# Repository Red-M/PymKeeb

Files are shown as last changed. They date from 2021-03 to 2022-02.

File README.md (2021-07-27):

# PymKeeb
## What is this?
I'm getting fed up with the options for keyboards and there isn't anything that I want 100%, everything is a compromise between form factor, customizability and availability.
So I'm making my own keyboard.

## Design choices
I don't want to limit end users on customizing their boards or choosing what they want, so I'll be maximumizing that as much as possible while also giving the option for changing things like the size and layout in forks or derivatives.
I don't want the host device to make choices for the user so limiting things behind having a certain OS is not ok, eg, software that runs on the host device.

## Goals
- USB C input
    - This is just a requirement at this point
- Layout
    - Full size layout with 4 extra switches above the numpad to set for macros
    - Indicator lights need to be above the numbpad
    - Two LEDs per switch, I want extra light
- Switches
    - Hot swap switches
        - Khali hotswaps allow for MX style switches to swap in and out
            - Has a number of switch variants that will fit
- Firmware/Software
    - Firmware only, no host device software at all.
    - Firmware updates should be really simple, no custom software, just drag and drop in DFU or similar
    - CapsLock indicator is in key and matches RGB light of switch
    - All on keyboard with function key similar to ducky keyboards
    - Brightness toggle
    - Macro support
    - NKRO
        - I don't want artifacts or ghosting at all

## Software for designing/building the board
KiCAD, you're going to need KiCAD.
I'm also learning KiCAD so please if you see something I've done that could be done a better way, please file at least an issue or go a head and fix it in a PR.
If it makes sense, I'll merge it in, no questions asked.

## Firmware
This is largely going to depend on what MCU I choose and right now all I know is that the pico or an STMF4 might be the best options.

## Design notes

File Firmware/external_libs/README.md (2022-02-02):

You're going to need these libraries:
- adafruit_bus_device
- adafruit_display_shapes
- adafruit_display_text
- adafruit_hid
- adafruit_rgb_display
- asyncio
- adafruit_dotstar
- adafruit_ducky
- adafruit_st7789
- adafruit_ticks

Make sure they're also in the lib directory of the CIRCUITPY drive after you copy everything from the Firmware directory.

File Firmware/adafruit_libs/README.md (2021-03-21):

You're going to need these libraries:
- adafruit_bus_device
- adafruit_hid
- adafruit_mcp230xx
- https://github.com/adafruit/Adafruit_CircuitPython_DotStar

Make sure they're also in the lib directory of the CIRCUITPY drive after you copy everything from the Firmware directory.

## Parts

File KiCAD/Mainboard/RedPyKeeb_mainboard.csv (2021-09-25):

Reference | Quantity | Value | Footprint | Datasheet | Digikey Part No | Mouser No | element14 code
C6 | 1 | EEE-FN1C102UV | Capacitor_SMD:CP_Elec_10x10 |  | 10-EEE-FN1C102UVCT-ND | 667-EEE-FN1C102UV
D0,0 D0,1 D0,2 D0,3 D0,4 D0,5 D1,0 D1,1 D1,2 D1,3 D1,4 D1,5 D2,0 D2,1 D2,2 D2,3 D2,4 D2,5 D3,0 D3,1 D3,2 D3,3 D3,4 D3,5 D4,0 D4,1 D4,2 D4,3 D4,4 D5,0 D5,1 D5,2 D5,3 D5,4 D6,0 D6,1 D6,2 D6,3 D6,4 D7,0 D7,1 D7,2 D7,3 D7,4 D8,0 D8,1 D8,2 D8,3 D8,4 D8,5 D9,0 D9,1 D9,2 D9,3 D9,4 D9,5 D10,0 D10,1 D10,2 D10,3 D10,4 D10,5 D11,0 D11,1 D11,2 D11,3 D11,4 D11,5 D12,0 D12,1 D12,2 D12,3 D13,1 D13,2 D14,0 D14,1 D14,3 D14,6 D15,0 D15,1 D15,3 D15,5 D15,6 D16,0 D16,1 D16,3 D16,4 D16,5 D16,6 D17,0 D17,1 D17,3 D17,4 D17,5 D17,6 D18,0 D18,1 D18,3 D18,4 D18,5 D18,6 D19,0 D19,1 D19,3 D19,4 D19,6 D20,0 D20,1 | 108 | 1N4148W-7-F | keyboard_parts:D_SOD123_axial |  | 1N4148W-FDICT-ND | 621-1N4148W-F | 2306363
J1 | 1 | Conn_02x20_Top_Bottom | Connector_PinHeader_2.54mm:PinHeader_2x20_P2.54mm_Vertical_SMD | ~ |  | 200-SSM120LMDVBE
LD0,0 LD0,1 LD0,2 LD0,3 LD0,4 LD0,5 LD1,0 LD1,1 LD1,2 LD1,3 LD1,4 LD1,5 LD2,0 LD2,1 LD2,2 LD2,3 LD2,4 LD2,5 LD3,0 LD3,1 LD3,2 LD3,3 LD3,4 LD3,5 LD4,0 LD4,1 LD4,2 LD4,3 LD4,4 LD5,0 LD5,1 LD5,2 LD5,3 LD5,4 LD6,0 LD6,1 LD6,2 LD6,3 LD6,4 LD7,0 LD7,1 LD7,2 LD7,3 LD7,4 LD8,0 LD8,1 LD8,2 LD8,3 LD8,4 LD8,5 LD9,0 LD9,1 LD9,2 LD9,3 LD9,4 LD9,5 LD10,0 LD10,1 LD10,2 LD10,3 LD10,4 LD10,5 LD11,0 LD11,1 LD11,2 LD11,3 LD11,4 LD11,5 LD12,0 LD12,1 LD12,2 LD12,3 LD13,1 LD13,2 LD14,0 LD14,1 LD14,3 LD14,6 LD15,0 LD15,1 LD15,3 LD15,5 LD15,6 LD16,0 LD16,1 LD16,3 LD16,4 LD16,5 LD16,6 LD17,0 LD17,1 LD17,3 LD17,4 LD17,5 LD17,6 LD17,7 LD18,0 LD18,1 LD18,3 LD18,4 LD18,5 LD18,6 LD18,7 LD19,0 LD19,1 LD19,3 LD19,4 LD19,6 LD19,7 LD20,0 LD20,1 LD20,7 LD3,5,0 LD3,5,1 | 114 | APA102 2020 | Custom_pico:LED-APA102-2020 | http://www.led-color.com/upload/201604/APA102-2020%20SMD%20LED.pdf | 1528-1826-ND | 485-3587

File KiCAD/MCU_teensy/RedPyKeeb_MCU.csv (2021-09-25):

Reference | Quantity | Value | Footprint | Datasheet | Digikey Part No | Mouser No | element14 code
C1 C2 | 2 | 0805B101K100CT | Capacitor_SMD:C_0805_2012Metric_Pad1.18x1.45mm_HandSolder |  |  | 791-0805B101K100CT | 1856401
J0 | 1 | Conn_01x04 | Connector_JST:JST_EH_S4B-EH_1x04_P2.50mm_Horizontal |  | 1528-2751-ND | 485-3955
J1 | 1 | Conn_02x20_Top_Bottom | Connector_PinHeader_2.54mm:PinHeader_2x20_P2.54mm_Vertical | ~ |  | 649-95278-102-40LF
J2 | 1 | Conn_01x04 | Connector_JST:JST_EH_S7B-EH_1x07_P2.50mm_Horizontal |  | 1528-2751-ND | 485-3955
R1 | 1 | ERJ-6RED2003V | Resistors_SMD:R_0805_HandSoldering | ~ |  | 667-ERJ-6RED2003V
U0 | 1 | Teensy4.1 | Custom_pico:Teensy41 |  |  | 474-DEV-16771
U1 | 1 | TXS0104ED | Package_SO:SOIC-14_3.9x8.7mm_P1.27mm | https://www.ti.com/lit/ds/symlink/txs0104e.pdf | 296-34699-5-ND | 595-TXS0104ED | TXS0104ED

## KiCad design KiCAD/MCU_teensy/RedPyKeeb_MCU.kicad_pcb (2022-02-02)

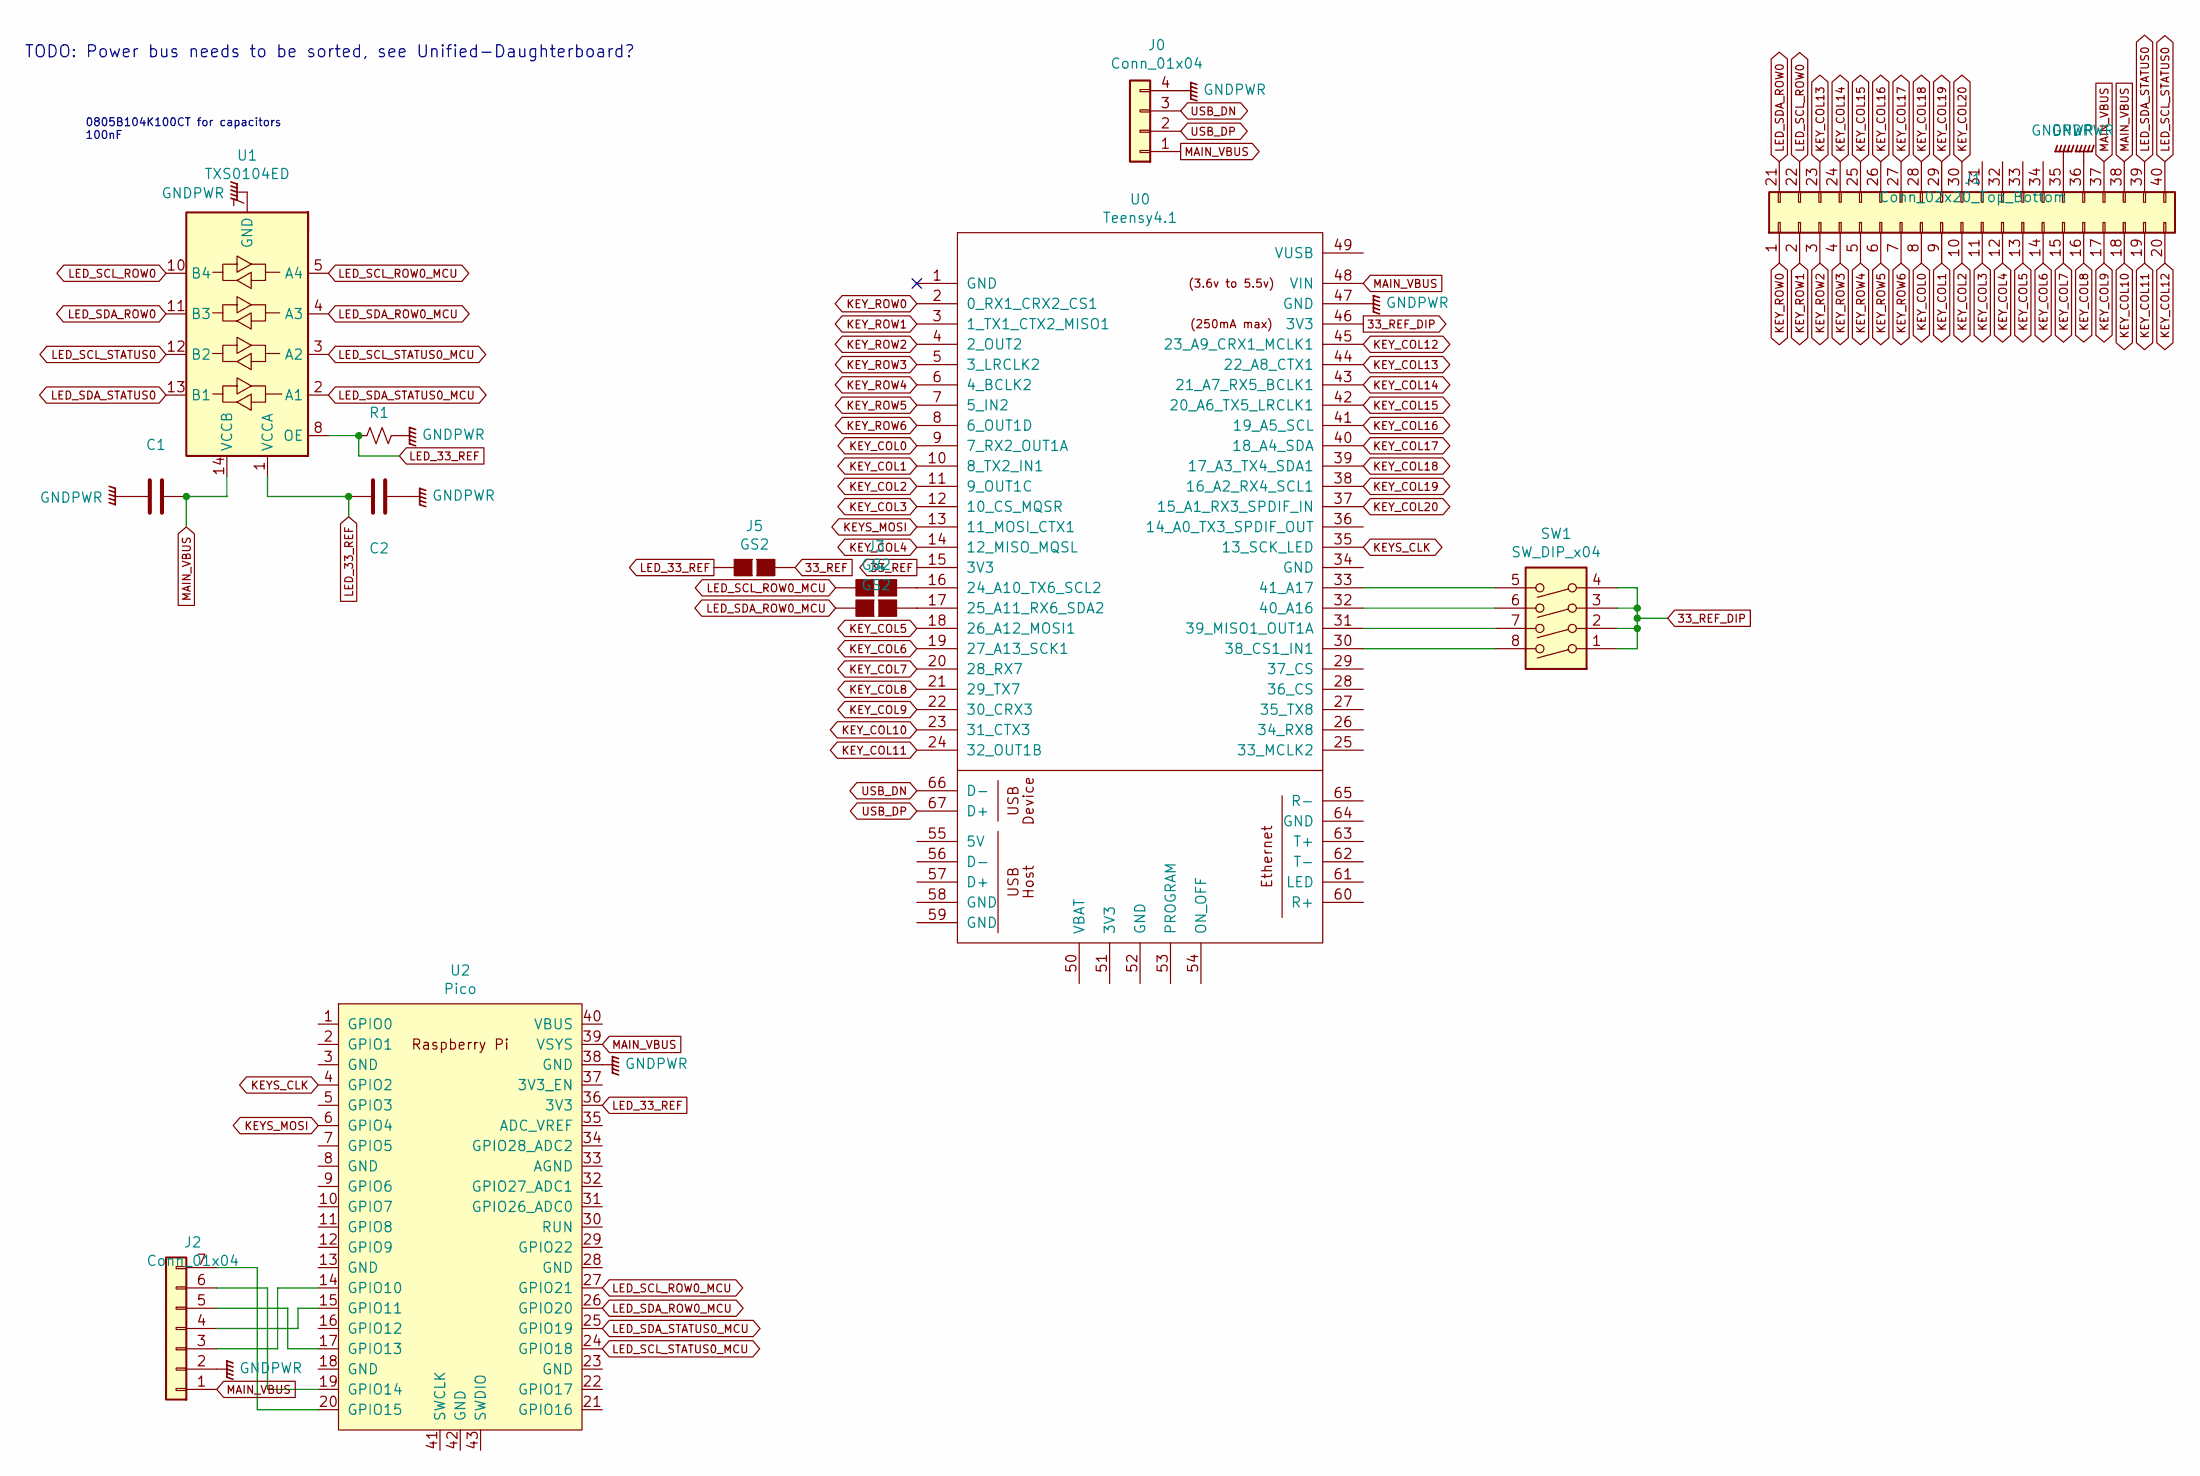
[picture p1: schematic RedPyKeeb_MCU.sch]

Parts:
C1, C2: 0805B101K100CT; C_0805_2012Metric_Pad1.18x1.45mm_HandSolder; Mouser No 791-0805B101K100CT
J0: Conn_01x04; JST_EH_S4B-EH_1x04_P2.50mm_Horizontal; Mouser No 485-3955
J1: Conn_02x20_Top_Bottom; PinHeader_2x20_P2.54mm_Vertical_SMD_doublesided; Mouser No 649-95278-102-40LF
J2: Conn_01x04; JST_EH_S7B-EH_1x07_P2.50mm_Horizontal; Mouser No 485-3955
J3, J4, J5: GS2
R1: ERJ-6RED2003V; R_0805_HandSoldering; Mouser No 667-ERJ-6RED2003V
SW1: SW_DIP_x04; SW_DIP_x4_W8.61mm_Slide_LowProfile_bothsides; Mouser No 653-A6SN-4104
U0: Teensy4.1; Teensy41; Mouser No 474-DEV-16771
U1: TXS0104ED; SOIC-14_3.9x8.7mm_P1.27mm; Mouser No 595-TXS0104ED
U2: Pico; RPi_Pico_SMD_TH

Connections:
33_REF: J5.1 (G1), U0.15 (3V3)
33_REF_DIP: SW1.1, SW1.2, SW1.3, SW1.4, U0.46 (3V3)
GNDPWR: C1.1, C2.1, J0.4, J1.35, J1.36, J2.2, R1.1, U0.47 (GND), U1.7 (GND), U2.38 (GND)
KEYS_CLK: U0.35 (13_SCK_LED), U2.4 (GPIO2)
KEYS_MOSI: U0.13 (11_MOSI_CTX1), U2.6 (GPIO4)
KEY_COL0: J1.8, U0.9 (7_RX2_OUT1A)
KEY_COL1: J1.9, U0.10 (8_TX2_IN1)
KEY_COL2: J1.10, U0.11 (9_OUT1C)
KEY_COL3: J1.11, U0.12 (10_CS_MQSR)
KEY_COL4: J1.12, U0.14 (12_MISO_MQSL)
KEY_COL5: J1.13, U0.18 (26_A12_MOSI1)
KEY_COL6: J1.14, U0.19 (27_A13_SCK1)
KEY_COL7: J1.15, U0.20 (28_RX7)
KEY_COL8: J1.16, U0.21 (29_TX7)
KEY_COL9: J1.17, U0.22 (30_CRX3)
KEY_COL10: J1.18, U0.23 (31_CTX3)
KEY_COL11: J1.19, U0.24 (32_OUT1B)
KEY_COL12: J1.20, U0.45 (23_A9_CRX1_MCLK1)
KEY_COL13: J1.23, U0.44 (22_A8_CTX1)
KEY_COL14: J1.24, U0.43 (21_A7_RX5_BCLK1)
KEY_COL15: J1.25, U0.42 (20_A6_TX5_LRCLK1)
KEY_COL16: J1.26, U0.41 (19_A5_SCL)
KEY_COL17: J1.27, U0.40 (18_A4_SDA)
KEY_COL18: J1.28, U0.39 (17_A3_TX4_SDA1)
KEY_COL19: J1.29, U0.38 (16_A2_RX4_SCL1)
KEY_COL20: J1.30, U0.37 (15_A1_RX3_SPDIF_IN)
KEY_ROW0: J1.1, U0.2 (0_RX1_CRX2_CS1)
KEY_ROW1: J1.2, U0.3 (1_TX1_CTX2_MISO1)
KEY_ROW2: J1.3, U0.4 (2_OUT2)
KEY_ROW3: J1.4, U0.5 (3_LRCLK2)
KEY_ROW4: J1.5, U0.6 (4_BCLK2)
KEY_ROW5: J1.6, U0.7 (5_IN2)
KEY_ROW6: J1.7, U0.8 (6_OUT1D)
LED_33_REF: C2.2, J5.2 (G2), R1.2, U1.1 (VCCA), U1.8 (OE), U2.36 (3V3)
LED_SCL_ROW0: J1.22, U1.10 (B4)
LED_SCL_ROW0_MCU: J3.2 (G2), U1.5 (A4), U2.27 (GPIO21)
LED_SCL_STATUS0: J1.40, U1.12 (B2)
LED_SCL_STATUS0_MCU: U1.3 (A2), U2.24 (GPIO18)
LED_SDA_ROW0: J1.21, U1.11 (B3)
LED_SDA_ROW0_MCU: J4.2 (G2), U1.4 (A3), U2.26 (GPIO20)
LED_SDA_STATUS0: J1.39, U1.13 (B1)
LED_SDA_STATUS0_MCU: U1.2 (A1), U2.25 (GPIO19)
MAIN_VBUS: C1.2, J0.1, J1.37, J1.38, J2.1, U0.48 (VIN), U1.14 (VCCB), U2.39 (VSYS)
unnamed: J2.3, U2.14 (GPIO10)
unnamed: J2.4, U2.15 (GPIO11)
unnamed: J2.5, U2.17 (GPIO13)
unnamed: J2.6, U2.19 (GPIO14)
unnamed: J2.7, U2.20 (GPIO15)
unnamed: J3.1 (G1), U0.16 (24_A10_TX6_SCL2)
unnamed: J4.1 (G1), U0.17 (25_A11_RX6_SDA2)
unnamed: SW1.5, U0.33 (41_A17)
unnamed: SW1.6, U0.32 (40_A16)
unnamed: SW1.7, U0.31 (39_MISO1_OUT1A)
unnamed: SW1.8, U0.30 (38_CS1_IN1)
USB_DN: J0.3, U0.66 (D-)
USB_DP: J0.2, U0.67 (D+)

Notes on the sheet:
TODO: Power bus needs to be sorted, see Unified-Daughterboard?
0805B104K100CT for capacitors 100nF

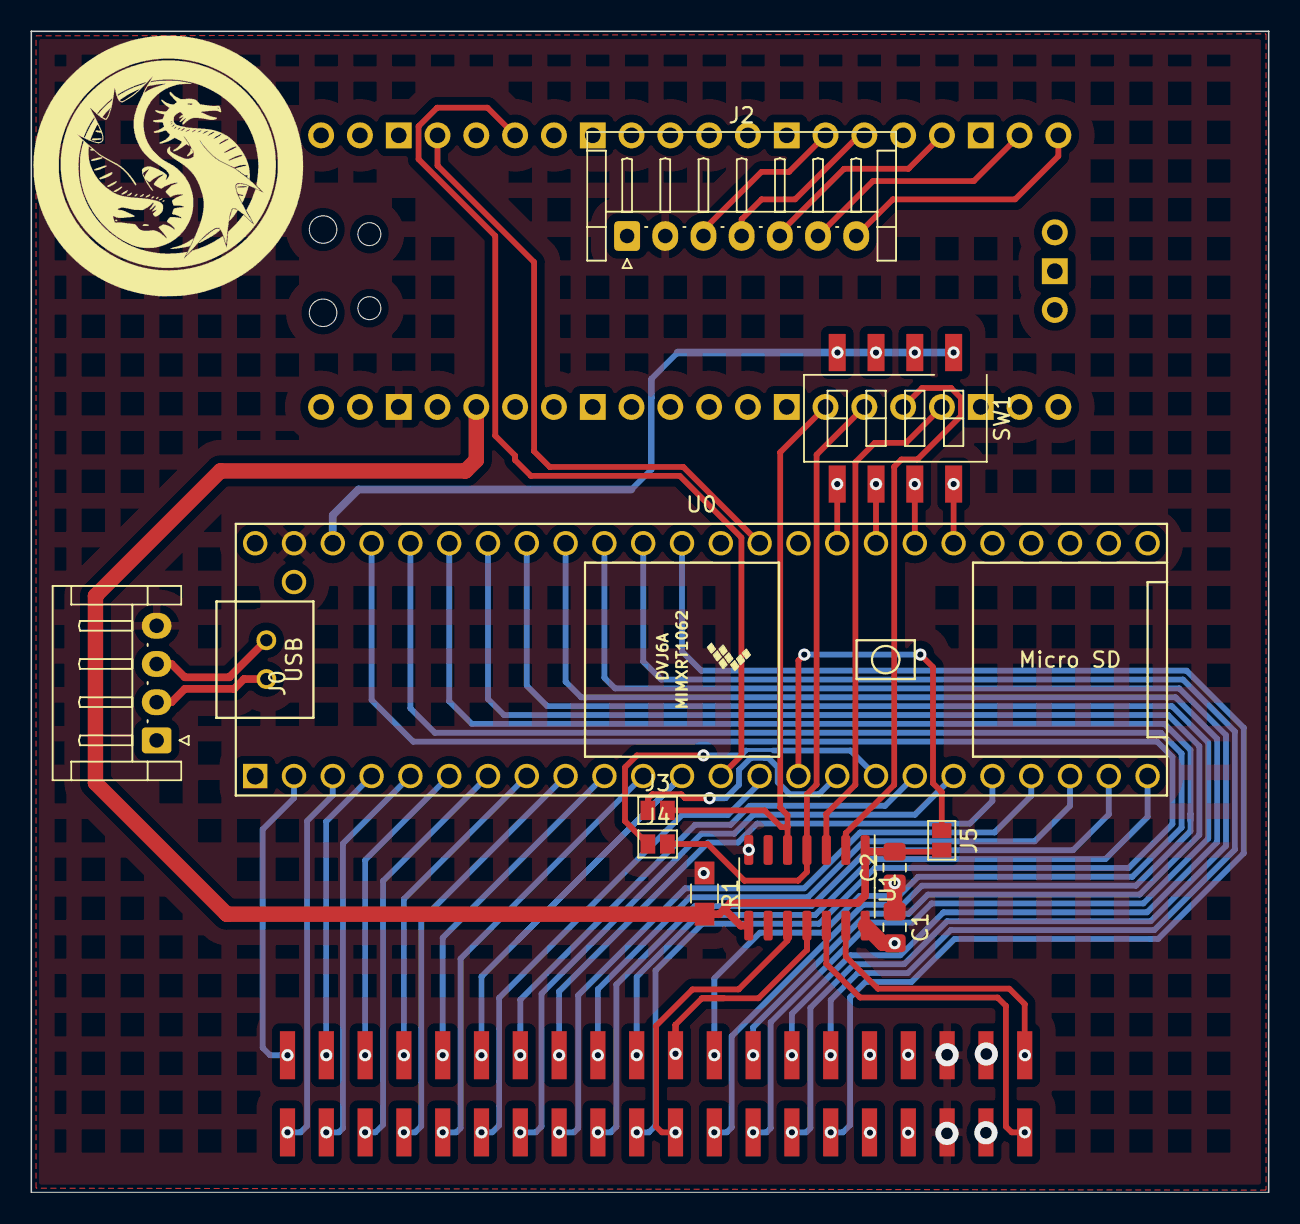
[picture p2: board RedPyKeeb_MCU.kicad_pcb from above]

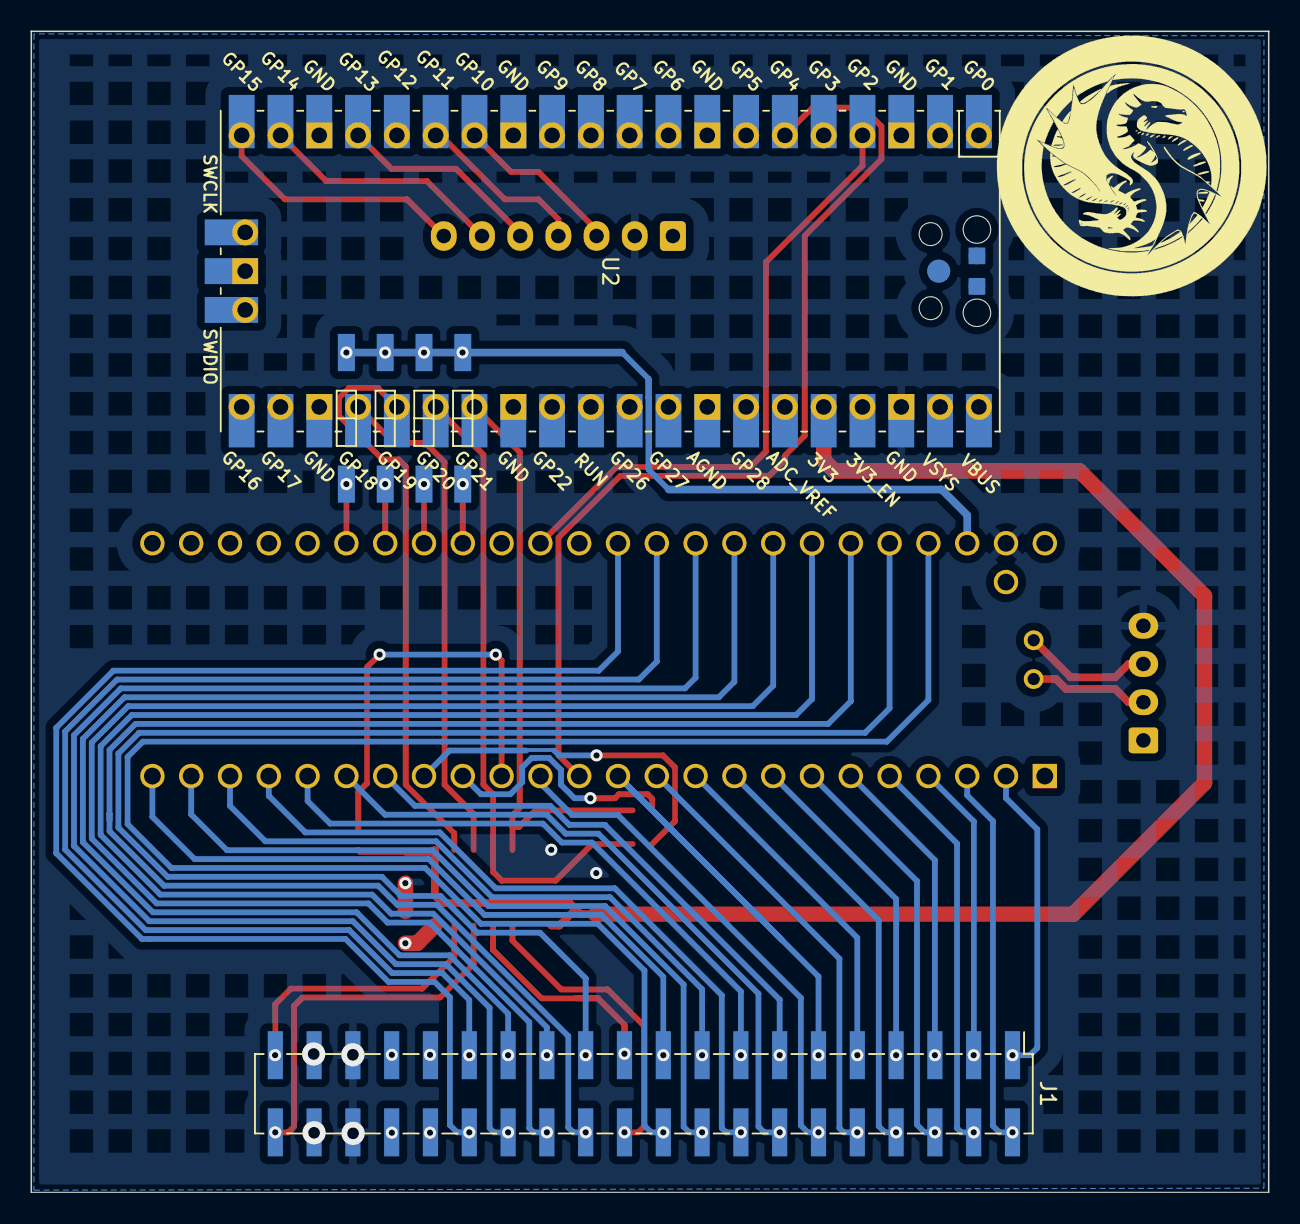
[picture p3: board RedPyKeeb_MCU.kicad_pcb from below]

Board: 4 copper layers, 81.0 x 76.0 mm, 13 parts (2 on the bottom side), 56 nets.

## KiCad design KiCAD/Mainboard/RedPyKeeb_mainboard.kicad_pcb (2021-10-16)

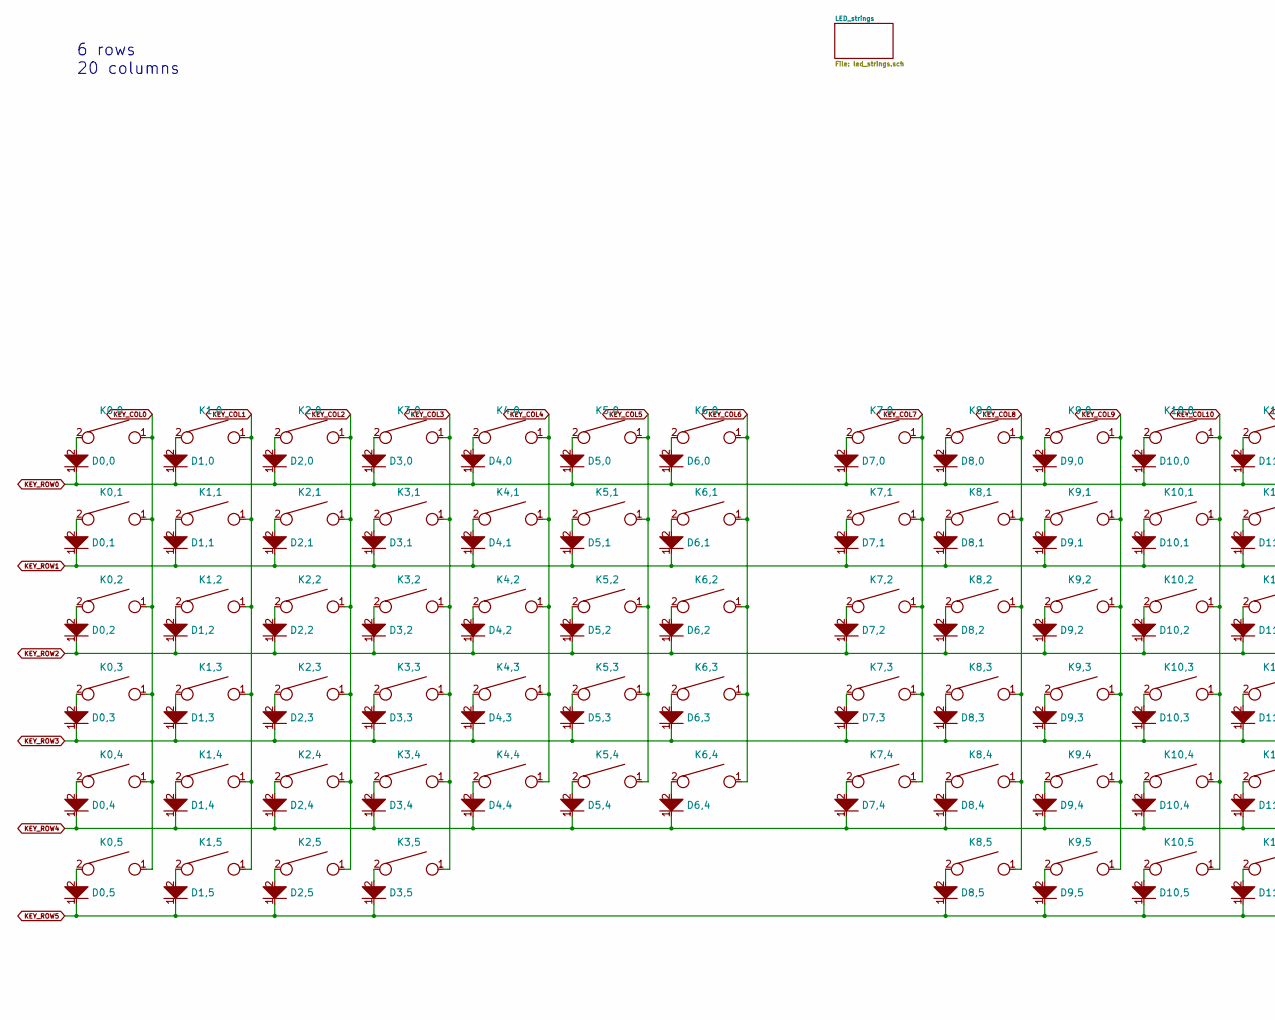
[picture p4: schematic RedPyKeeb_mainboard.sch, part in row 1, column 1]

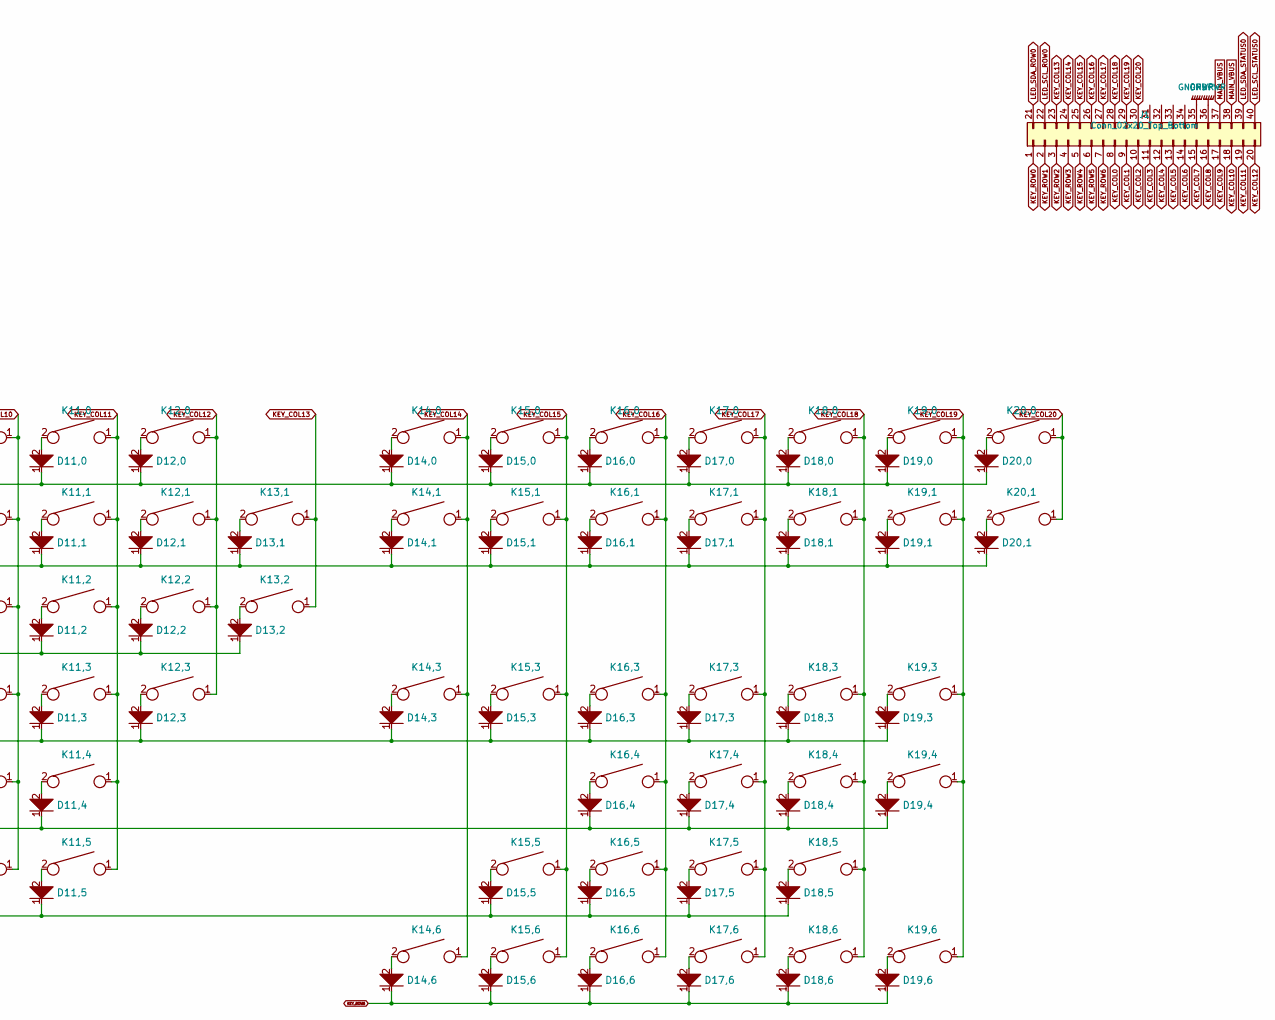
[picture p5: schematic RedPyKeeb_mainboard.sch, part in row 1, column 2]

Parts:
D0,0, D0,1, D0,2, D0,3, D0,4, D0,5, D1,0, D1,1, D1,2, D1,3, D1,4, D1,5, D2,0, D2,1, D2,2, D2,3, D2,4, D2,5, D3,0, D3,1, D3,2, D3,3, D3,4, D3,5, D4,0, D4,1, D4,2, D4,3, D4,4, D5,0, D5,1, D5,2, D5,3, D5,4, D6,0, D6,1, D6,2, D6,3, D6,4, D7,0, D7,1, D7,2, D7,3, D7,4, D8,0, D8,1, D8,2, D8,3, D8,4, D8,5, D9,0, D9,1, D9,2, D9,3, D9,4, D9,5, D10,0, D10,1, D10,2, D10,3, D10,4, D10,5, D11,0, D11,1, D11,2, D11,3, D11,4, D11,5, D12,0, D12,1, D12,2, D12,3, D13,1, D13,2, D14,0, D14,1, D14,3, D14,6, D15,0, D15,1, D15,3, D15,5, D15,6, D16,0, D16,1, D16,3, D16,4, D16,5, D16,6, D17,0, D17,1, D17,3, D17,4, D17,5, D17,6, D18,0, D18,1, D18,3, D18,4, D18,5, D18,6, D19,0, D19,1, D19,3, D19,4, D19,6, D20,0, D20,1: 1N4148W-7-F; D_SOD123_axial; Mouser No 621-1N4148W-F
J1: Conn_02x20_Top_Bottom; PinHeader_2x20_P2.54mm_Vertical_SMD_doublesided; Mouser No 200-SSM120LMDVBE
K0,0, K0,1, K1,0, K1,1, K1,2, K1,3, K1,4, K2,0, K2,1, K2,2, K2,3, K2,4, K3,0, K3,1, K3,2, K3,3, K3,4, K4,0, K4,1, K4,2, K4,3, K4,4, K5,0, K5,1, K5,2, K5,3, K5,4, K6,0, K6,1, K6,2, K6,3, K6,4, K7,0, K7,1, K7,2, K7,3, K7,4, K8,0, K8,1, K8,2, K8,3, K8,4, K9,0, K9,1, K9,2, K9,3, K9,4, K10,0, K10,1, K10,2, K10,3, K10,4, K11,0, K11,1, K11,2, K11,3, K12,0, K12,1, K12,2, K14,0, K14,1, K14,3, K14,6, K15,0, K15,1, K15,3, K15,5, K15,6, K16,0, K16,1, K16,3, K16,4, K16,5, K16,6, K17,0, K17,1, K17,3, K17,4, K17,5, K18,0, K18,1, K18,3, K18,4, K18,5, K18,6, K19,0, K19,1, K19,3, K20,0, K20,1: SW_Hotswap_Kailh_1.00u
K0,2, K13,2: SW_Hotswap_Kailh_1.50u
K0,3: SW_Hotswap_Kailh_1.75u
K0,4, K12,3: SW_Hotswap_Kailh_2.25u
K0,5, K1,5, K2,5, K8,5, K9,5, K10,5, K11,5: SW_Hotswap_Kailh_1.25u
K3,5: SW_Hotswap_Kailh_6.25u
K11,4: SW_Hotswap_Kailh_2.75u
K13,1, K17,6: SW_Hotswap_Kailh_2.00u
K19,4, K19,6: SW_Hotswap_Kailh_2.00u_Rotated

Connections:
GNDPWR: J1.35, J1.36; also elsewhere on the board
KEY_COL0: J1.8, K0,0.1, K0,1.1, K0,2.1, K0,3.1, K0,4.1, K0,5.1
KEY_COL1: J1.9, K1,0.1, K1,1.1, K1,2.1, K1,3.1, K1,4.1, K1,5.1
KEY_COL2: J1.10, K2,0.1, K2,1.1, K2,2.1, K2,3.1, K2,4.1, K2,5.1
KEY_COL3: J1.11, K3,0.1, K3,1.1, K3,2.1, K3,3.1, K3,4.1, K3,5.1
KEY_COL4: J1.12, K4,0.1, K4,1.1, K4,2.1, K4,3.1, K4,4.1
KEY_COL5: J1.13, K5,0.1, K5,1.1, K5,2.1, K5,3.1, K5,4.1
KEY_COL6: J1.14, K6,0.1, K6,1.1, K6,2.1, K6,3.1, K6,4.1
KEY_COL7: J1.15, K7,0.1, K7,1.1, K7,2.1, K7,3.1, K7,4.1
KEY_COL8: J1.16, K8,0.1, K8,1.1, K8,2.1, K8,3.1, K8,4.1, K8,5.1
KEY_COL9: J1.17, K9,0.1, K9,1.1, K9,2.1, K9,3.1, K9,4.1, K9,5.1
KEY_COL10: J1.18, K10,0.1, K10,1.1, K10,2.1, K10,3.1, K10,4.1, K10,5.1
KEY_COL11: J1.19, K11,0.1, K11,1.1, K11,2.1, K11,3.1, K11,4.1, K11,5.1
KEY_COL12: J1.20, K12,0.1, K12,1.1, K12,2.1, K12,3.1
KEY_COL13: J1.23, K13,1.1, K13,2.1
KEY_COL14: J1.24, K14,0.1, K14,1.1, K14,3.1, K14,6.1
KEY_COL15: J1.25, K15,0.1, K15,1.1, K15,3.1, K15,5.1, K15,6.1
KEY_COL16: J1.26, K16,0.1, K16,1.1, K16,3.1, K16,4.1, K16,5.1, K16,6.1
KEY_COL17: J1.27, K17,0.1, K17,1.1, K17,3.1, K17,4.1, K17,5.1, K17,6.1
KEY_COL18: J1.28, K18,0.1, K18,1.1, K18,3.1, K18,4.1, K18,5.1, K18,6.1
KEY_COL19: J1.29, K19,0.1, K19,1.1, K19,3.1, K19,4.1, K19,6.1
KEY_COL20: J1.30, K20,0.1, K20,1.1
KEY_ROW0: D0,0.1, D1,0.1, D2,0.1, D3,0.1, D4,0.1, D5,0.1, D6,0.1, D7,0.1, D8,0.1, D9,0.1, D10,0.1, D11,0.1, D12,0.1, D14,0.1, D15,0.1, D16,0.1, D17,0.1, D18,0.1, D19,0.1, D20,0.1, J1.1
KEY_ROW1: D0,1.1, D1,1.1, D2,1.1, D3,1.1, D4,1.1, D5,1.1, D6,1.1, D7,1.1, D8,1.1, D9,1.1, D10,1.1, D11,1.1, D12,1.1, D13,1.1, D14,1.1, D15,1.1, D16,1.1, D17,1.1, D18,1.1, D19,1.1, D20,1.1, J1.2
KEY_ROW2: D0,2.1, D1,2.1, D2,2.1, D3,2.1, D4,2.1, D5,2.1, D6,2.1, D7,2.1, D8,2.1, D9,2.1, D10,2.1, D11,2.1, D12,2.1, D13,2.1, J1.3
KEY_ROW3: D0,3.1, D1,3.1, D2,3.1, D3,3.1, D4,3.1, D5,3.1, D6,3.1, D7,3.1, D8,3.1, D9,3.1, D10,3.1, D11,3.1, D12,3.1, D14,3.1, D15,3.1, D16,3.1, D17,3.1, D18,3.1, D19,3.1, J1.4
KEY_ROW4: D0,4.1, D1,4.1, D2,4.1, D3,4.1, D4,4.1, D5,4.1, D6,4.1, D7,4.1, D8,4.1, D9,4.1, D10,4.1, D11,4.1, D16,4.1, D17,4.1, D18,4.1, D19,4.1, J1.5
KEY_ROW5: D0,5.1, D1,5.1, D2,5.1, D3,5.1, D8,5.1, D9,5.1, D10,5.1, D11,5.1, D15,5.1, D16,5.1, D17,5.1, D18,5.1, J1.6
KEY_ROW6: D14,6.1, D15,6.1, D16,6.1, D17,6.1, D18,6.1, D19,6.1, J1.7
LED_SCL_ROW0: J1.22; also elsewhere on the board
LED_SCL_STATUS0: J1.40; also elsewhere on the board
LED_SDA_ROW0: J1.21; also elsewhere on the board
LED_SDA_STATUS0: J1.39; also elsewhere on the board
MAIN_VBUS: J1.37, J1.38; also elsewhere on the board
unnamed: D0,0.2, K0,0.2
unnamed: D0,1.2, K0,1.2
unnamed: D0,2.2, K0,2.2
unnamed: D0,3.2, K0,3.2
unnamed: D0,4.2, K0,4.2
unnamed: D0,5.2, K0,5.2
unnamed: D1,0.2, K1,0.2
unnamed: D1,1.2, K1,1.2
unnamed: D1,2.2, K1,2.2
unnamed: D1,3.2, K1,3.2
unnamed: D1,4.2, K1,4.2
unnamed: D1,5.2, K1,5.2
unnamed: D2,0.2, K2,0.2
unnamed: D2,1.2, K2,1.2
unnamed: D2,2.2, K2,2.2
unnamed: D2,3.2, K2,3.2
unnamed: D2,4.2, K2,4.2
unnamed: D2,5.2, K2,5.2
unnamed: D3,0.2, K3,0.2
unnamed: D3,1.2, K3,1.2
unnamed: D3,2.2, K3,2.2
unnamed: D3,3.2, K3,3.2
unnamed: D3,4.2, K3,4.2
unnamed: D3,5.2, K3,5.2
unnamed: D4,0.2, K4,0.2
unnamed: D4,1.2, K4,1.2
unnamed: D4,2.2, K4,2.2
unnamed: D4,3.2, K4,3.2
unnamed: D4,4.2, K4,4.2
unnamed: D5,0.2, K5,0.2
unnamed: D5,1.2, K5,1.2
unnamed: D5,2.2, K5,2.2
unnamed: D5,3.2, K5,3.2
unnamed: D5,4.2, K5,4.2
unnamed: D6,0.2, K6,0.2
unnamed: D6,1.2, K6,1.2
unnamed: D6,2.2, K6,2.2
unnamed: D6,3.2, K6,3.2
unnamed: D6,4.2, K6,4.2
unnamed: D7,0.2, K7,0.2
unnamed: D7,1.2, K7,1.2
unnamed: D7,2.2, K7,2.2
unnamed: D7,3.2, K7,3.2
unnamed: D7,4.2, K7,4.2
unnamed: D8,0.2, K8,0.2
unnamed: D8,1.2, K8,1.2
unnamed: D8,2.2, K8,2.2
unnamed: D8,3.2, K8,3.2
unnamed: D8,4.2, K8,4.2
unnamed: D8,5.2, K8,5.2
unnamed: D9,0.2, K9,0.2
unnamed: D9,1.2, K9,1.2
unnamed: D9,2.2, K9,2.2
unnamed: D9,3.2, K9,3.2
unnamed: D9,4.2, K9,4.2
unnamed: D9,5.2, K9,5.2
unnamed: D10,0.2, K10,0.2
unnamed: D10,1.2, K10,1.2
unnamed: D10,2.2, K10,2.2
unnamed: D10,3.2, K10,3.2
unnamed: D10,4.2, K10,4.2
unnamed: D10,5.2, K10,5.2
unnamed: D11,0.2, K11,0.2
unnamed: D11,1.2, K11,1.2
unnamed: D11,2.2, K11,2.2
unnamed: D11,3.2, K11,3.2
unnamed: D11,4.2, K11,4.2
unnamed: D11,5.2, K11,5.2
unnamed: D12,0.2, K12,0.2
unnamed: D12,1.2, K12,1.2
unnamed: D12,2.2, K12,2.2
unnamed: D12,3.2, K12,3.2
unnamed: D13,1.2, K13,1.2
unnamed: D13,2.2, K13,2.2
unnamed: D14,0.2, K14,0.2
unnamed: D14,1.2, K14,1.2
unnamed: D14,3.2, K14,3.2
unnamed: D14,6.2, K14,6.2
unnamed: D15,0.2, K15,0.2
unnamed: D15,1.2, K15,1.2
unnamed: D15,3.2, K15,3.2
unnamed: D15,5.2, K15,5.2
unnamed: D15,6.2, K15,6.2
unnamed: D16,0.2, K16,0.2
unnamed: D16,1.2, K16,1.2
unnamed: D16,3.2, K16,3.2
unnamed: D16,4.2, K16,4.2
unnamed: D16,5.2, K16,5.2
unnamed: D16,6.2, K16,6.2
unnamed: D17,0.2, K17,0.2
unnamed: D17,1.2, K17,1.2
unnamed: D17,3.2, K17,3.2
unnamed: D17,4.2, K17,4.2
unnamed: D17,5.2, K17,5.2
unnamed: D17,6.2, K17,6.2
unnamed: D18,0.2, K18,0.2
unnamed: D18,1.2, K18,1.2
unnamed: D18,3.2, K18,3.2
unnamed: D18,4.2, K18,4.2
unnamed: D18,5.2, K18,5.2
unnamed: D18,6.2, K18,6.2
unnamed: D19,0.2, K19,0.2
unnamed: D19,1.2, K19,1.2
unnamed: D19,3.2, K19,3.2
unnamed: D19,4.2, K19,4.2
unnamed: D19,6.2, K19,6.2
unnamed: D20,0.2, K20,0.2
unnamed: D20,1.2, K20,1.2

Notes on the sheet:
6 rows 20 columns

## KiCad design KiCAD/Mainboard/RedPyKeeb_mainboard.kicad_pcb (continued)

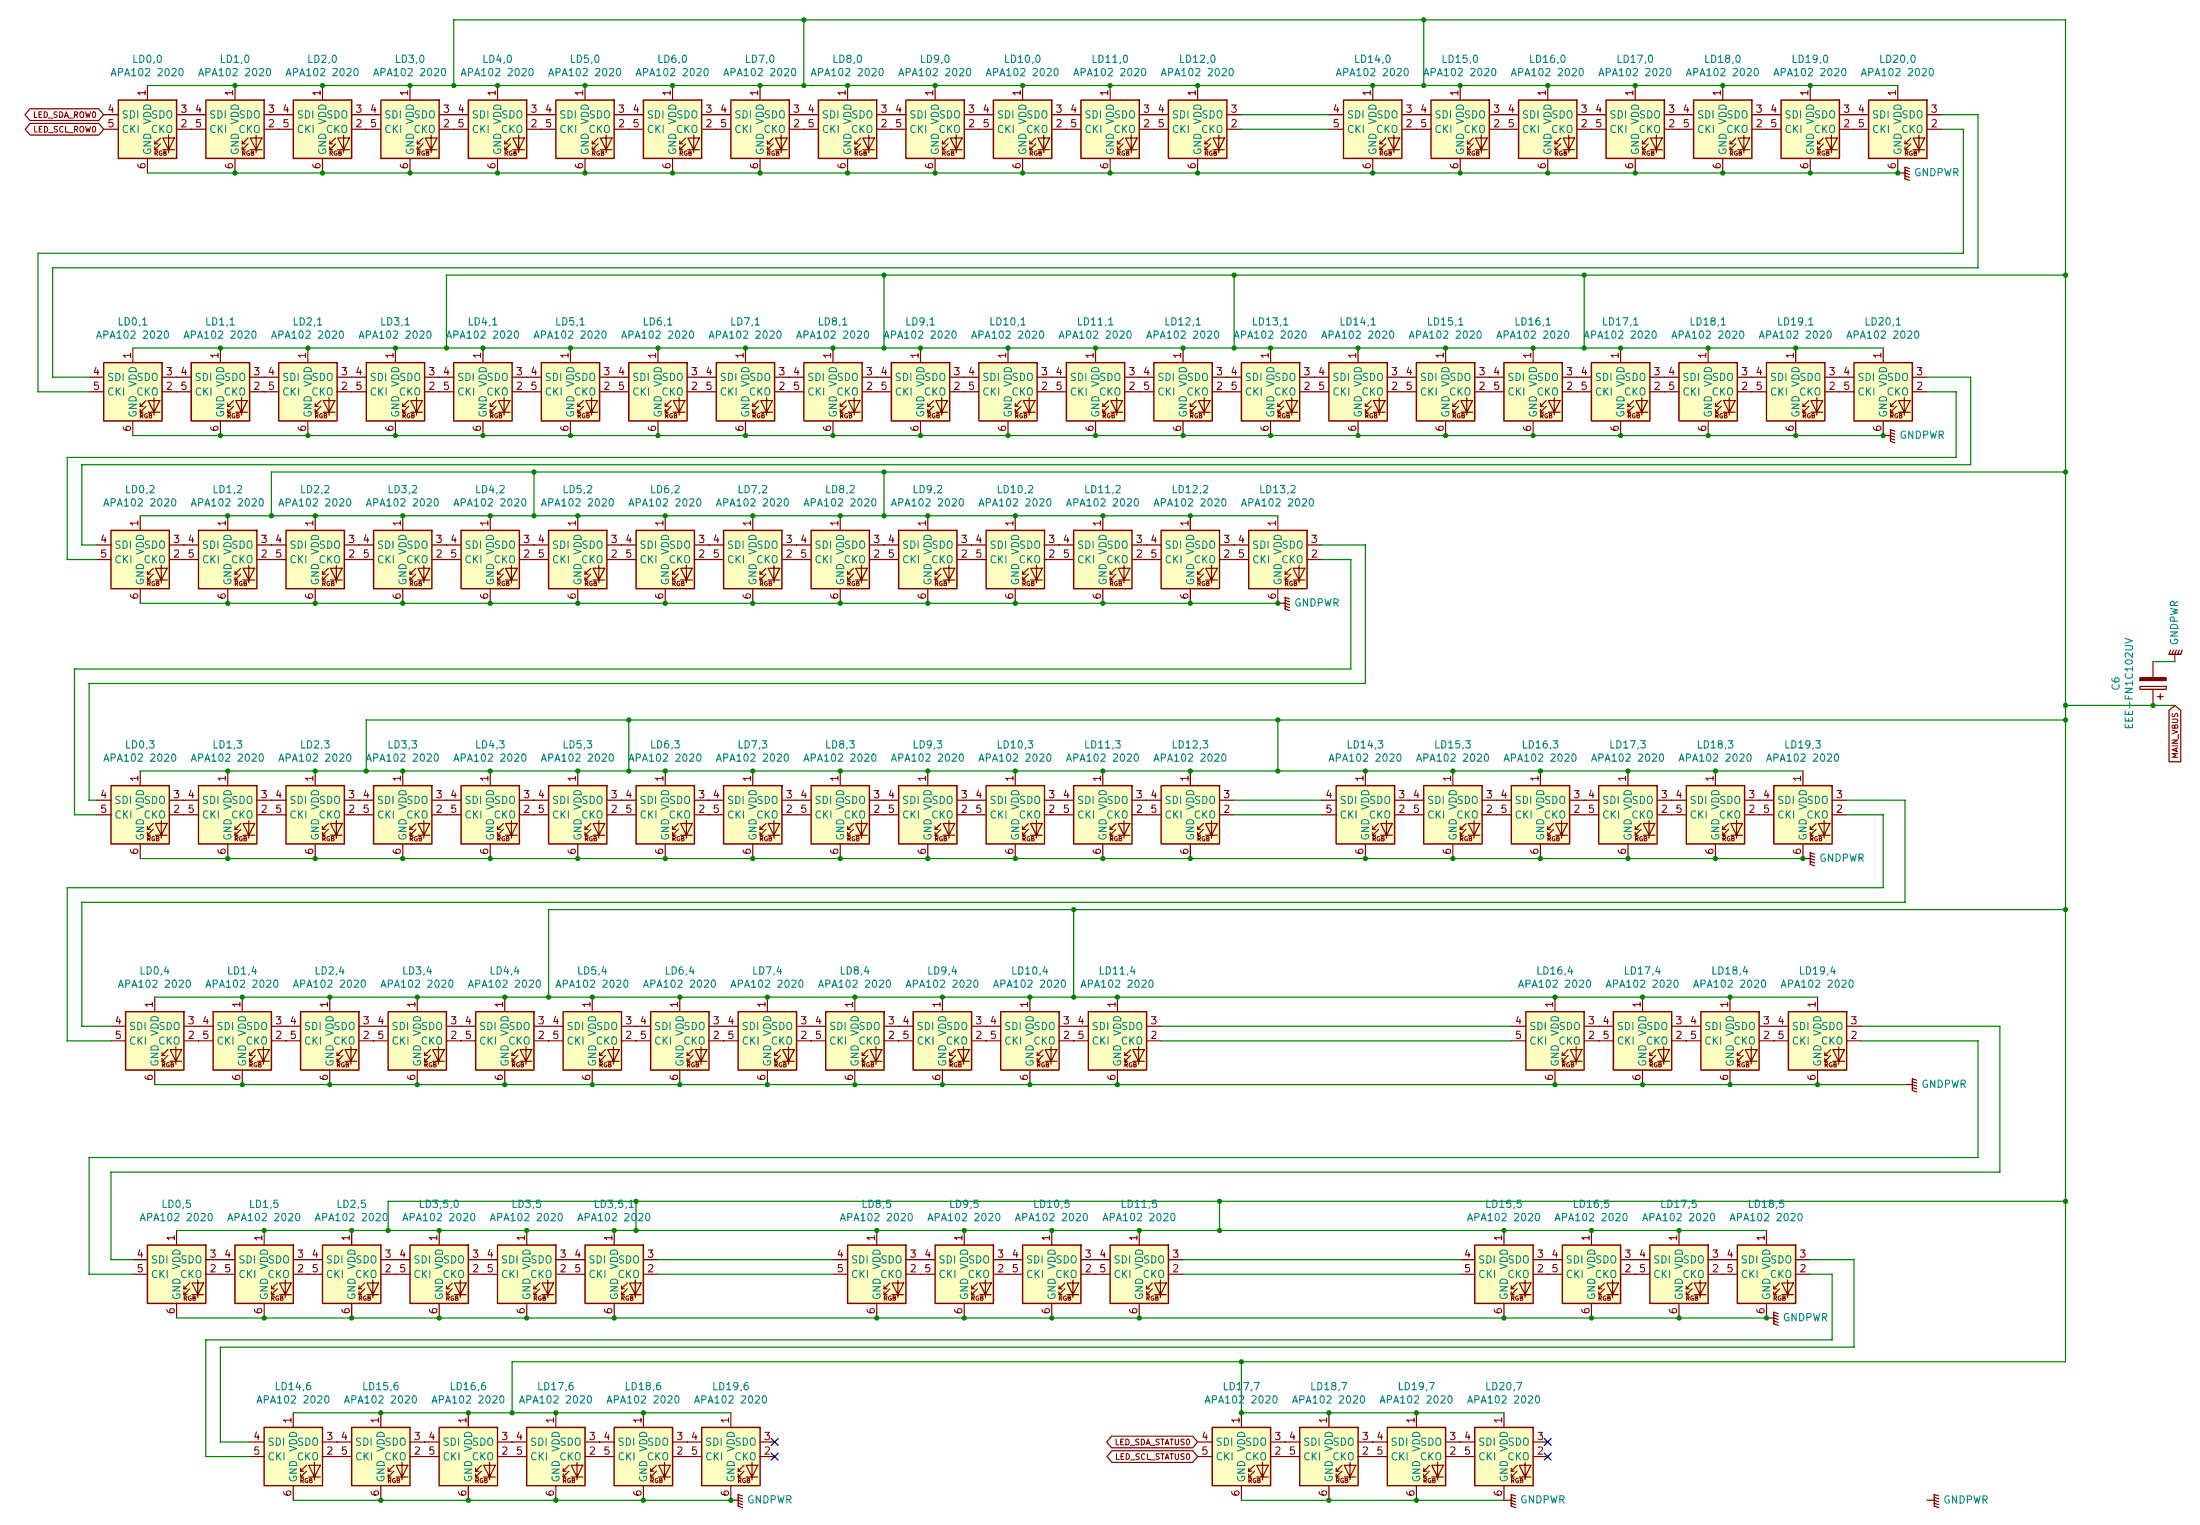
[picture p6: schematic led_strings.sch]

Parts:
C6: EEE-FN1C102UV; CP_Elec_10x10; Mouser No 667-EEE-FN1C102UV
LD0,0, LD0,1, LD0,2, LD0,3, LD0,4, LD0,5, LD1,0, LD1,1, LD1,2, LD1,3, LD1,4, LD1,5, LD2,0, LD2,1, LD2,2, LD2,3, LD2,4, LD2,5, LD3,0, LD3,1, LD3,2, LD3,3, LD3,4, LD3,5, LD3,5,0, LD3,5,1, LD4,0, LD4,1, LD4,2, LD4,3, LD4,4, LD5,0, LD5,1, LD5,2, LD5,3, LD5,4, LD6,0, LD6,1, LD6,2, LD6,3, LD6,4, LD7,0, LD7,1, LD7,2, LD7,3, LD7,4, LD8,0, LD8,1, LD8,2, LD8,3, LD8,4, LD8,5, LD9,0, LD9,1, LD9,2, LD9,3, LD9,4, LD9,5, LD10,0, LD10,1, LD10,2, LD10,3, LD10,4, LD10,5, LD11,0, LD11,1, LD11,2, LD11,3, LD11,4, LD11,5, LD12,0, LD12,1, LD12,2, LD12,3, LD13,1, LD13,2, LD14,0, LD14,1, LD14,3, LD14,6, LD15,0, LD15,1, LD15,3, LD15,5, LD15,6, LD16,0, LD16,1, LD16,3, LD16,4, LD16,5, LD16,6, LD17,0, LD17,1, LD17,3, LD17,4, LD17,5, LD17,6, LD17,7, LD18,0, LD18,1, LD18,3, LD18,4, LD18,5, LD18,6, LD18,7, LD19,0, LD19,1, LD19,3, LD19,4, LD19,6, LD19,7, LD20,0, LD20,1, LD20,7: APA102 2020; LED-APA102-2020; Mouser No 485-3587

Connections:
GNDPWR: C6.2, LD0,0.6 (GND), LD0,1.6 (GND), LD0,2.6 (GND), LD0,3.6 (GND), LD0,4.6 (GND), LD0,5.6 (GND), LD1,0.6 (GND), LD1,1.6 (GND), LD1,2.6 (GND), LD1,3.6 (GND), LD1,4.6 (GND), LD1,5.6 (GND), LD2,0.6 (GND), LD2,1.6 (GND), LD2,2.6 (GND), LD2,3.6 (GND), LD2,4.6 (GND), LD2,5.6 (GND), LD3,0.6 (GND), LD3,1.6 (GND), LD3,2.6 (GND), LD3,3.6 (GND), LD3,4.6 (GND), LD3,5.6 (GND), LD3,5,0.6 (GND), LD3,5,1.6 (GND), LD4,0.6 (GND), LD4,1.6 (GND), LD4,2.6 (GND), LD4,3.6 (GND), LD4,4.6 (GND), LD5,0.6 (GND), LD5,1.6 (GND), LD5,2.6 (GND), LD5,3.6 (GND), LD5,4.6 (GND), LD6,0.6 (GND), LD6,1.6 (GND), LD6,2.6 (GND), LD6,3.6 (GND), LD6,4.6 (GND), LD7,0.6 (GND), LD7,1.6 (GND), LD7,2.6 (GND), LD7,3.6 (GND), LD7,4.6 (GND), LD8,0.6 (GND), LD8,1.6 (GND), LD8,2.6 (GND), LD8,3.6 (GND), LD8,4.6 (GND), LD8,5.6 (GND), LD9,0.6 (GND), LD9,1.6 (GND), LD9,2.6 (GND), LD9,3.6 (GND), LD9,4.6 (GND), LD9,5.6 (GND), LD10,0.6 (GND), LD10,1.6 (GND), LD10,2.6 (GND), LD10,3.6 (GND), LD10,4.6 (GND), LD10,5.6 (GND), LD11,0.6 (GND), LD11,1.6 (GND), LD11,2.6 (GND), LD11,3.6 (GND), LD11,4.6 (GND), LD11,5.6 (GND), LD12,0.6 (GND), LD12,1.6 (GND), LD12,2.6 (GND), LD12,3.6 (GND), LD13,1.6 (GND), LD13,2.6 (GND), LD14,0.6 (GND), LD14,1.6 (GND), LD14,3.6 (GND), LD14,6.6 (GND), LD15,0.6 (GND), LD15,1.6 (GND), LD15,3.6 (GND), LD15,5.6 (GND), LD15,6.6 (GND), LD16,0.6 (GND), LD16,1.6 (GND), LD16,3.6 (GND), LD16,4.6 (GND), LD16,5.6 (GND), LD16,6.6 (GND), LD17,0.6 (GND), LD17,1.6 (GND), LD17,3.6 (GND), LD17,4.6 (GND), LD17,5.6 (GND), LD17,6.6 (GND), LD17,7.6 (GND), LD18,0.6 (GND), LD18,1.6 (GND), LD18,3.6 (GND), LD18,4.6 (GND), LD18,5.6 (GND), LD18,6.6 (GND), LD18,7.6 (GND), LD19,0.6 (GND), LD19,1.6 (GND), LD19,3.6 (GND), LD19,4.6 (GND), LD19,6.6 (GND), LD19,7.6 (GND), LD20,0.6 (GND), LD20,1.6 (GND), LD20,7.6 (GND); also elsewhere on the board
LED_SCL_ROW0: LD0,0.5 (CKI); also elsewhere on the board
LED_SCL_STATUS0: LD17,7.5 (CKI); also elsewhere on the board
LED_SDA_ROW0: LD0,0.4 (SDI); also elsewhere on the board
LED_SDA_STATUS0: LD17,7.4 (SDI); also elsewhere on the board
MAIN_VBUS: C6.1, LD0,0.1 (VDD), LD0,1.1 (VDD), LD0,2.1 (VDD), LD0,3.1 (VDD), LD0,4.1 (VDD), LD0,5.1 (VDD), LD1,0.1 (VDD), LD1,1.1 (VDD), LD1,2.1 (VDD), LD1,3.1 (VDD), LD1,4.1 (VDD), LD1,5.1 (VDD), LD2,0.1 (VDD), LD2,1.1 (VDD), LD2,2.1 (VDD), LD2,3.1 (VDD), LD2,4.1 (VDD), LD2,5.1 (VDD), LD3,0.1 (VDD), LD3,1.1 (VDD), LD3,2.1 (VDD), LD3,3.1 (VDD), LD3,4.1 (VDD), LD3,5.1 (VDD), LD3,5,0.1 (VDD), LD3,5,1.1 (VDD), LD4,0.1 (VDD), LD4,1.1 (VDD), LD4,2.1 (VDD), LD4,3.1 (VDD), LD4,4.1 (VDD), LD5,0.1 (VDD), LD5,1.1 (VDD), LD5,2.1 (VDD), LD5,3.1 (VDD), LD5,4.1 (VDD), LD6,0.1 (VDD), LD6,1.1 (VDD), LD6,2.1 (VDD), LD6,3.1 (VDD), LD6,4.1 (VDD), LD7,0.1 (VDD), LD7,1.1 (VDD), LD7,2.1 (VDD), LD7,3.1 (VDD), LD7,4.1 (VDD), LD8,0.1 (VDD), LD8,1.1 (VDD), LD8,2.1 (VDD), LD8,3.1 (VDD), LD8,4.1 (VDD), LD8,5.1 (VDD), LD9,0.1 (VDD), LD9,1.1 (VDD), LD9,2.1 (VDD), LD9,3.1 (VDD), LD9,4.1 (VDD), LD9,5.1 (VDD), LD10,0.1 (VDD), LD10,1.1 (VDD), LD10,2.1 (VDD), LD10,3.1 (VDD), LD10,4.1 (VDD), LD10,5.1 (VDD), LD11,0.1 (VDD), LD11,1.1 (VDD), LD11,2.1 (VDD), LD11,3.1 (VDD), LD11,4.1 (VDD), LD11,5.1 (VDD), LD12,0.1 (VDD), LD12,1.1 (VDD), LD12,2.1 (VDD), LD12,3.1 (VDD), LD13,1.1 (VDD), LD13,2.1 (VDD), LD14,0.1 (VDD), LD14,1.1 (VDD), LD14,3.1 (VDD), LD14,6.1 (VDD), LD15,0.1 (VDD), LD15,1.1 (VDD), LD15,3.1 (VDD), LD15,5.1 (VDD), LD15,6.1 (VDD), LD16,0.1 (VDD), LD16,1.1 (VDD), LD16,3.1 (VDD), LD16,4.1 (VDD), LD16,5.1 (VDD), LD16,6.1 (VDD), LD17,0.1 (VDD), LD17,1.1 (VDD), LD17,3.1 (VDD), LD17,4.1 (VDD), LD17,5.1 (VDD), LD17,6.1 (VDD), LD17,7.1 (VDD), LD18,0.1 (VDD), LD18,1.1 (VDD), LD18,3.1 (VDD), LD18,4.1 (VDD), LD18,5.1 (VDD), LD18,6.1 (VDD), LD18,7.1 (VDD), LD19,0.1 (VDD), LD19,1.1 (VDD), LD19,3.1 (VDD), LD19,4.1 (VDD), LD19,6.1 (VDD), LD19,7.1 (VDD), LD20,0.1 (VDD), LD20,1.1 (VDD), LD20,7.1 (VDD); also elsewhere on the board
unnamed: LD0,0.2 (CKO), LD1,0.5 (CKI)
unnamed: LD0,0.3 (SDO), LD1,0.4 (SDI)
unnamed: LD0,1.2 (CKO), LD1,1.5 (CKI)
unnamed: LD0,1.3 (SDO), LD1,1.4 (SDI)
unnamed: LD0,1.4 (SDI), LD20,0.3 (SDO)
unnamed: LD0,1.5 (CKI), LD20,0.2 (CKO)
unnamed: LD0,2.2 (CKO), LD1,2.5 (CKI)
unnamed: LD0,2.3 (SDO), LD1,2.4 (SDI)
unnamed: LD0,2.4 (SDI), LD20,1.3 (SDO)
unnamed: LD0,2.5 (CKI), LD20,1.2 (CKO)
unnamed: LD0,3.2 (CKO), LD1,3.5 (CKI)
unnamed: LD0,3.3 (SDO), LD1,3.4 (SDI)
unnamed: LD0,3.4 (SDI), LD13,2.3 (SDO)
unnamed: LD0,3.5 (CKI), LD13,2.2 (CKO)
unnamed: LD0,4.2 (CKO), LD1,4.5 (CKI)
unnamed: LD0,4.3 (SDO), LD1,4.4 (SDI)
unnamed: LD0,4.4 (SDI), LD19,3.3 (SDO)
unnamed: LD0,4.5 (CKI), LD19,3.2 (CKO)
unnamed: LD0,5.2 (CKO), LD1,5.5 (CKI)
unnamed: LD0,5.3 (SDO), LD1,5.4 (SDI)
unnamed: LD0,5.4 (SDI), LD19,4.3 (SDO)
unnamed: LD0,5.5 (CKI), LD19,4.2 (CKO)
unnamed: LD1,0.2 (CKO), LD2,0.5 (CKI)
unnamed: LD1,0.3 (SDO), LD2,0.4 (SDI)
unnamed: LD1,1.2 (CKO), LD2,1.5 (CKI)
unnamed: LD1,1.3 (SDO), LD2,1.4 (SDI)
unnamed: LD1,2.2 (CKO), LD2,2.5 (CKI)
unnamed: LD1,2.3 (SDO), LD2,2.4 (SDI)
unnamed: LD1,3.2 (CKO), LD2,3.5 (CKI)
unnamed: LD1,3.3 (SDO), LD2,3.4 (SDI)
unnamed: LD1,4.2 (CKO), LD2,4.5 (CKI)
unnamed: LD1,4.3 (SDO), LD2,4.4 (SDI)
unnamed: LD1,5.2 (CKO), LD2,5.5 (CKI)
unnamed: LD1,5.3 (SDO), LD2,5.4 (SDI)
unnamed: LD2,0.2 (CKO), LD3,0.5 (CKI)
unnamed: LD2,0.3 (SDO), LD3,0.4 (SDI)
unnamed: LD2,1.2 (CKO), LD3,1.5 (CKI)
unnamed: LD2,1.3 (SDO), LD3,1.4 (SDI)
unnamed: LD2,2.2 (CKO), LD3,2.5 (CKI)
unnamed: LD2,2.3 (SDO), LD3,2.4 (SDI)
unnamed: LD2,3.2 (CKO), LD3,3.5 (CKI)
unnamed: LD2,3.3 (SDO), LD3,3.4 (SDI)
unnamed: LD2,4.2 (CKO), LD3,4.5 (CKI)
unnamed: LD2,4.3 (SDO), LD3,4.4 (SDI)
unnamed: LD2,5.2 (CKO), LD3,5,0.5 (CKI)
unnamed: LD2,5.3 (SDO), LD3,5,0.4 (SDI)
unnamed: LD3,0.2 (CKO), LD4,0.5 (CKI)
unnamed: LD3,0.3 (SDO), LD4,0.4 (SDI)
unnamed: LD3,1.2 (CKO), LD4,1.5 (CKI)
unnamed: LD3,1.3 (SDO), LD4,1.4 (SDI)
unnamed: LD3,2.2 (CKO), LD4,2.5 (CKI)
unnamed: LD3,2.3 (SDO), LD4,2.4 (SDI)
unnamed: LD3,3.2 (CKO), LD4,3.5 (CKI)
unnamed: LD3,3.3 (SDO), LD4,3.4 (SDI)
unnamed: LD3,4.2 (CKO), LD4,4.5 (CKI)
unnamed: LD3,4.3 (SDO), LD4,4.4 (SDI)
unnamed: LD3,5.5 (CKI), LD3,5,0.2 (CKO)
unnamed: LD3,5.4 (SDI), LD3,5,0.3 (SDO)
unnamed: LD3,5,1.2 (CKO), LD8,5.5 (CKI)
unnamed: LD3,5,1.3 (SDO), LD8,5.4 (SDI)
unnamed: LD3,5.3 (SDO), LD3,5,1.4 (SDI)
unnamed: LD3,5.2 (CKO), LD3,5,1.5 (CKI)
unnamed: LD4,0.2 (CKO), LD5,0.5 (CKI)
unnamed: LD4,0.3 (SDO), LD5,0.4 (SDI)
unnamed: LD4,1.2 (CKO), LD5,1.5 (CKI)
unnamed: LD4,1.3 (SDO), LD5,1.4 (SDI)
unnamed: LD4,2.2 (CKO), LD5,2.5 (CKI)
unnamed: LD4,2.3 (SDO), LD5,2.4 (SDI)
unnamed: LD4,3.2 (CKO), LD5,3.5 (CKI)
unnamed: LD4,3.3 (SDO), LD5,3.4 (SDI)
unnamed: LD4,4.2 (CKO), LD5,4.5 (CKI)
unnamed: LD4,4.3 (SDO), LD5,4.4 (SDI)
unnamed: LD5,0.2 (CKO), LD6,0.5 (CKI)
unnamed: LD5,0.3 (SDO), LD6,0.4 (SDI)
unnamed: LD5,1.2 (CKO), LD6,1.5 (CKI)
unnamed: LD5,1.3 (SDO), LD6,1.4 (SDI)
unnamed: LD5,2.2 (CKO), LD6,2.5 (CKI)
unnamed: LD5,2.3 (SDO), LD6,2.4 (SDI)
unnamed: LD5,3.2 (CKO), LD6,3.5 (CKI)
unnamed: LD5,3.3 (SDO), LD6,3.4 (SDI)
unnamed: LD5,4.2 (CKO), LD6,4.5 (CKI)
unnamed: LD5,4.3 (SDO), LD6,4.4 (SDI)
unnamed: LD6,0.2 (CKO), LD7,0.5 (CKI)
unnamed: LD6,0.3 (SDO), LD7,0.4 (SDI)
unnamed: LD6,1.2 (CKO), LD7,1.5 (CKI)
unnamed: LD6,1.3 (SDO), LD7,1.4 (SDI)
unnamed: LD6,2.2 (CKO), LD7,2.5 (CKI)
unnamed: LD6,2.3 (SDO), LD7,2.4 (SDI)
unnamed: LD6,3.2 (CKO), LD7,3.5 (CKI)
unnamed: LD6,3.3 (SDO), LD7,3.4 (SDI)
unnamed: LD6,4.2 (CKO), LD7,4.5 (CKI)
unnamed: LD6,4.3 (SDO), LD7,4.4 (SDI)
unnamed: LD7,0.2 (CKO), LD8,0.5 (CKI)
unnamed: LD7,0.3 (SDO), LD8,0.4 (SDI)
unnamed: LD7,1.2 (CKO), LD8,1.5 (CKI)
unnamed: LD7,1.3 (SDO), LD8,1.4 (SDI)
unnamed: LD7,2.2 (CKO), LD8,2.5 (CKI)
unnamed: LD7,2.3 (SDO), LD8,2.4 (SDI)
unnamed: LD7,3.2 (CKO), LD8,3.5 (CKI)
unnamed: LD7,3.3 (SDO), LD8,3.4 (SDI)
unnamed: LD7,4.2 (CKO), LD8,4.5 (CKI)
unnamed: LD7,4.3 (SDO), LD8,4.4 (SDI)
unnamed: LD8,0.2 (CKO), LD9,0.5 (CKI)
unnamed: LD8,0.3 (SDO), LD9,0.4 (SDI)
unnamed: LD8,1.2 (CKO), LD9,1.5 (CKI)
unnamed: LD8,1.3 (SDO), LD9,1.4 (SDI)
unnamed: LD8,2.2 (CKO), LD9,2.5 (CKI)
unnamed: LD8,2.3 (SDO), LD9,2.4 (SDI)
unnamed: LD8,3.2 (CKO), LD9,3.5 (CKI)
unnamed: LD8,3.3 (SDO), LD9,3.4 (SDI)
unnamed: LD8,4.2 (CKO), LD9,4.5 (CKI)
unnamed: LD8,4.3 (SDO), LD9,4.4 (SDI)
unnamed: LD8,5.2 (CKO), LD9,5.5 (CKI)
unnamed: LD8,5.3 (SDO), LD9,5.4 (SDI)
unnamed: LD10,0.2 (CKO), LD11,0.5 (CKI)
unnamed: LD10,0.3 (SDO), LD11,0.4 (SDI)
unnamed: LD9,0.3 (SDO), LD10,0.4 (SDI)
unnamed: LD9,0.2 (CKO), LD10,0.5 (CKI)
unnamed: LD10,1.2 (CKO), LD11,1.5 (CKI)
unnamed: LD10,1.3 (SDO), LD11,1.4 (SDI)
unnamed: LD9,1.3 (SDO), LD10,1.4 (SDI)
unnamed: LD9,1.2 (CKO), LD10,1.5 (CKI)
unnamed: LD10,2.2 (CKO), LD11,2.5 (CKI)
unnamed: LD10,2.3 (SDO), LD11,2.4 (SDI)
unnamed: LD9,2.3 (SDO), LD10,2.4 (SDI)
unnamed: LD9,2.2 (CKO), LD10,2.5 (CKI)
unnamed: LD10,3.2 (CKO), LD11,3.5 (CKI)
unnamed: LD10,3.3 (SDO), LD11,3.4 (SDI)
unnamed: LD9,3.3 (SDO), LD10,3.4 (SDI)
unnamed: LD9,3.2 (CKO), LD10,3.5 (CKI)
unnamed: LD10,4.2 (CKO), LD11,4.5 (CKI)
unnamed: LD10,4.3 (SDO), LD11,4.4 (SDI)
unnamed: LD9,4.3 (SDO), LD10,4.4 (SDI)
unnamed: LD9,4.2 (CKO), LD10,4.5 (CKI)
unnamed: LD10,5.2 (CKO), LD11,5.5 (CKI)
unnamed: LD10,5.3 (SDO), LD11,5.4 (SDI)
unnamed: LD9,5.3 (SDO), LD10,5.4 (SDI)
unnamed: LD9,5.2 (CKO), LD10,5.5 (CKI)
unnamed: LD11,0.2 (CKO), LD12,0.5 (CKI)
unnamed: LD11,0.3 (SDO), LD12,0.4 (SDI)
unnamed: LD11,1.2 (CKO), LD12,1.5 (CKI)
unnamed: LD11,1.3 (SDO), LD12,1.4 (SDI)
unnamed: LD11,2.2 (CKO), LD12,2.5 (CKI)
unnamed: LD11,2.3 (SDO), LD12,2.4 (SDI)
unnamed: LD11,3.2 (CKO), LD12,3.5 (CKI)
unnamed: LD11,3.3 (SDO), LD12,3.4 (SDI)
unnamed: LD11,4.2 (CKO), LD16,4.5 (CKI)
unnamed: LD11,4.3 (SDO), LD16,4.4 (SDI)
unnamed: LD11,5.2 (CKO), LD15,5.5 (CKI)
unnamed: LD11,5.3 (SDO), LD15,5.4 (SDI)
unnamed: LD12,0.2 (CKO), LD14,0.5 (CKI)
unnamed: LD12,0.3 (SDO), LD14,0.4 (SDI)
unnamed: LD12,1.2 (CKO), LD13,1.5 (CKI)
unnamed: LD12,1.3 (SDO), LD13,1.4 (SDI)
unnamed: LD12,2.2 (CKO), LD13,2.5 (CKI)
unnamed: LD12,2.3 (SDO), LD13,2.4 (SDI)
unnamed: LD12,3.2 (CKO), LD14,3.5 (CKI)
unnamed: LD12,3.3 (SDO), LD14,3.4 (SDI)
unnamed: LD13,1.2 (CKO), LD14,1.5 (CKI)
unnamed: LD13,1.3 (SDO), LD14,1.4 (SDI)
unnamed: LD14,0.2 (CKO), LD15,0.5 (CKI)
unnamed: LD14,0.3 (SDO), LD15,0.4 (SDI)
unnamed: LD14,1.2 (CKO), LD15,1.5 (CKI)
unnamed: LD14,1.3 (SDO), LD15,1.4 (SDI)
unnamed: LD14,3.2 (CKO), LD15,3.5 (CKI)
unnamed: LD14,3.3 (SDO), LD15,3.4 (SDI)
unnamed: LD14,6.2 (CKO), LD15,6.5 (CKI)
unnamed: LD14,6.3 (SDO), LD15,6.4 (SDI)
unnamed: LD14,6.4 (SDI), LD18,5.3 (SDO)
unnamed: LD14,6.5 (CKI), LD18,5.2 (CKO)
unnamed: LD15,0.2 (CKO), LD16,0.5 (CKI)
unnamed: LD15,0.3 (SDO), LD16,0.4 (SDI)
unnamed: LD15,1.2 (CKO), LD16,1.5 (CKI)
unnamed: LD15,1.3 (SDO), LD16,1.4 (SDI)
unnamed: LD15,3.2 (CKO), LD16,3.5 (CKI)
unnamed: LD15,3.3 (SDO), LD16,3.4 (SDI)
unnamed: LD15,5.2 (CKO), LD16,5.5 (CKI)
unnamed: LD15,5.3 (SDO), LD16,5.4 (SDI)
unnamed: LD15,6.2 (CKO), LD16,6.5 (CKI)
unnamed: LD15,6.3 (SDO), LD16,6.4 (SDI)
unnamed: LD16,0.2 (CKO), LD17,0.5 (CKI)
unnamed: LD16,0.3 (SDO), LD17,0.4 (SDI)
unnamed: LD16,1.2 (CKO), LD17,1.5 (CKI)
unnamed: LD16,1.3 (SDO), LD17,1.4 (SDI)
unnamed: LD16,3.2 (CKO), LD17,3.5 (CKI)
unnamed: LD16,3.3 (SDO), LD17,3.4 (SDI)
unnamed: LD16,4.2 (CKO), LD17,4.5 (CKI)
unnamed: LD16,4.3 (SDO), LD17,4.4 (SDI)
unnamed: LD16,5.2 (CKO), LD17,5.5 (CKI)
unnamed: LD16,5.3 (SDO), LD17,5.4 (SDI)
unnamed: LD16,6.2 (CKO), LD17,6.5 (CKI)
unnamed: LD16,6.3 (SDO), LD17,6.4 (SDI)
unnamed: LD17,0.2 (CKO), LD18,0.5 (CKI)
unnamed: LD17,0.3 (SDO), LD18,0.4 (SDI)
unnamed: LD17,1.2 (CKO), LD18,1.5 (CKI)
unnamed: LD17,1.3 (SDO), LD18,1.4 (SDI)
unnamed: LD17,3.2 (CKO), LD18,3.5 (CKI)
unnamed: LD17,3.3 (SDO), LD18,3.4 (SDI)
unnamed: LD17,4.2 (CKO), LD18,4.5 (CKI)
unnamed: LD17,4.3 (SDO), LD18,4.4 (SDI)
unnamed: LD17,5.2 (CKO), LD18,5.5 (CKI)
unnamed: LD17,5.3 (SDO), LD18,5.4 (SDI)
unnamed: LD17,6.2 (CKO), LD18,6.5 (CKI)
unnamed: LD17,6.3 (SDO), LD18,6.4 (SDI)
unnamed: LD17,7.2 (CKO), LD18,7.5 (CKI)
unnamed: LD17,7.3 (SDO), LD18,7.4 (SDI)
unnamed: LD18,0.2 (CKO), LD19,0.5 (CKI)
unnamed: LD18,0.3 (SDO), LD19,0.4 (SDI)
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

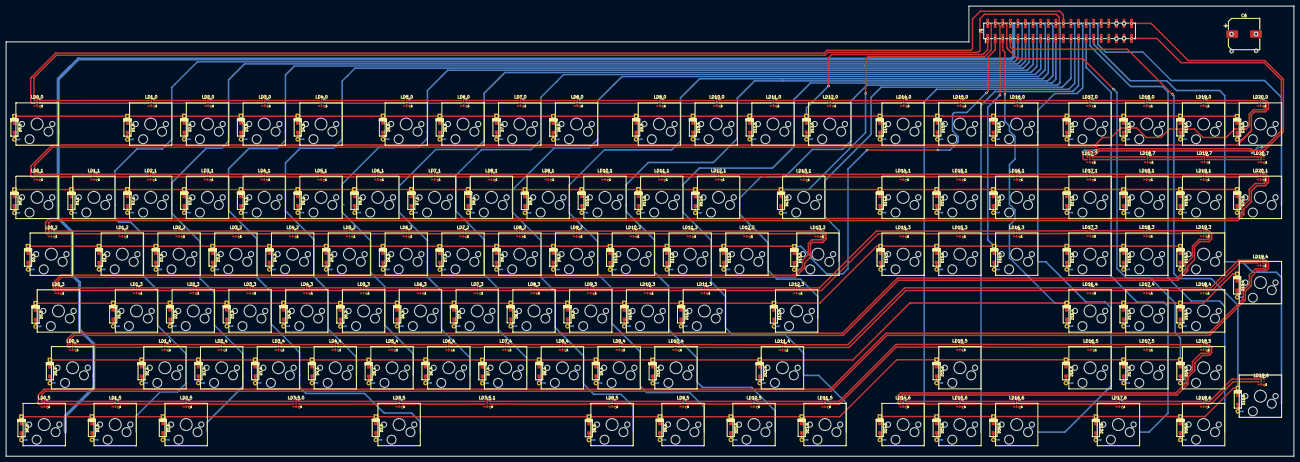
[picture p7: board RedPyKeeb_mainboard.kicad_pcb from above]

Board: 4 copper layers, 432.0 x 151.0 mm, 333 parts (1 on the bottom side), 366 nets.

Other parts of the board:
C6#2: EEE-FN1C102UV; CP_Elec_10x10

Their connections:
GNDPWR: C6#2.2; also elsewhere on the board
MAIN_VBUS: C6#2.1; also elsewhere on the board

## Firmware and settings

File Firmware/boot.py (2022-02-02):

import board
import storage
import usb_cdc
import usb_hid
import usb_midi
from digitalio import DigitalInOut, Direction, Pull

import main_controller

main_c = main_controller.main

if main_c==True:
    HYBRID_KEYBOARD_DESCRIPTOR_REPORT_ID=7
    HYBRID_REPORT_BYTES=24
    hybrid_keyboard_descriptor=bytes((
        0x05, 0x01,                         # Usage Page (Generic Desktop),
        0x09, 0x06,                         # Usage (Keyboard),
        0xA1, 0x01,                         # Collection (Application),
        0x85, 0x07,                         #   6,7 Report ID  [SET AT RUNTIME]
        # hybrid of modifiers
        0x75, 0x01,                         #   Report Size (1),
        0x95, 0x08,                         #   Report Count (8),
        0x05, 0x07,                         #   Usage Page (Key Codes),
        0x19, 0xE0,                         #   Usage Minimum (224),
        0x29, 0xE7,                         #   Usage Maximum (231),
        0x15, 0x00,                         #   Logical Minimum (0),
        0x25, 0x01,                         #   Logical Maximum (1),
        0x81, 0x02,                         #   Input (Data, Variable, Absolute), ;Modifier byte
        # LED output report
        0x95, 0x05,                         #   Report Count (5),
        0x75, 0x01,                         #   Report Size (1),
        0x05, 0x08,                         #   Usage Page (LEDs),
        0x19, 0x01,                         #   Usage Minimum (1),
        0x29, 0x05,                         #   Usage Maximum (5),
        0x91, 0x02,                         #   Output (Data, Variable, Absolute),
        0x95, 0x01,                         #   Report Count (1),
        0x75, 0x03,                         #   Report Size (3),
        0x91, 0x03,                         #   Output (Constant),
        # Padding / fake boot keyboard
        0x95, 0x38,                         #   Report Count (56),
        0x75, 0x01,                         #   Report Size (1),
        0x81, 0x01,                         #   Input (Const,Array,Abs,No Wrap,Linear,Preferred State,No Null Position)

        # hybrid of keys
        0x95, (HYBRID_REPORT_BYTES-8)*8,    #   Report Count (),
        0x75, 0x01,                         #   Report Size (1),
        0x15, 0x00,                         #   Logical Minimum (0),
        0x25, 0x01,                         #   Logical Maximum(1),
        0x05, 0x07,                         #   Usage Page (Key Codes),
        0x19, 0x00,                         #   Usage Minimum (0),
        0x29, (HYBRID_REPORT_BYTES-8)*8-1,  #   Usage Maximum (),
        0x81, 0x02,                         #   Input (Data, Variable, Absolute),
        0xc0                                # End Collection
    ))

    hybrid_keyboard = usb_hid.Device(
        report_descriptor=hybrid_keyboard_descriptor,
        usage_page=0x1,
        usage=0x6,
        in_report_lengths=(HYBRID_REPORT_BYTES,),
        out_report_lengths=(1,),
        report_ids=(HYBRID_KEYBOARD_DESCRIPTOR_REPORT_ID,),
    )


    usb_devices = [
        hybrid_keyboard,
        usb_hid.Device.KEYBOARD,
        usb_hid.Device.CONSUMER_CONTROL,
        usb_hid.Device.MOUSE,
    ]
else:
    usb_devices = []

pin_on = True
pin_off = False
if main_c==True:
    dip_pins = [
        DigitalInOut(board.D38),
        DigitalInOut(board.D39),
        DigitalInOut(board.D40),
        DigitalInOut(board.D41)
    ]
    six_kro_select = dip_pins[0]
    usb3_power = dip_pins[1]
    dip_pin3 = dip_pins[2]
    debug_mode = dip_pins[3]

    six_kro_select.switch_to_input(Pull.DOWN)
    usb3_power.switch_to_input(Pull.DOWN)
    debug_mode.switch_to_input(Pull.DOWN)
    if main_c==True:
        if six_kro_select.value==pin_on:
            del usb_devices[0]
        elif six_kro_select.value==pin_off:
            del usb_devices[1]

    global USB_POWER_ALLOWANCE
    if usb3_power.value==pin_on:
        USB_POWER_ALLOWANCE = 900
    else:
        USB_POWER_ALLOWANCE = 500

    if debug_mode.value==pin_on: # flip for release boards
        storage.disable_usb_drive() # CIRCUITPY drive
        usb_cdc.disable() # REPL

    for pin in dip_pins:
        pin.deinit()
    del dip_pins

usb_midi.disable()
usb_hid.enable(usb_devices)

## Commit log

2021-03-07 Add initial files.
    [RedPyKeeb.kicad_pcb, RedPyKeeb.sch]
2021-03-10 Update KiCAD files
    [key_matrix.sch]
2021-03-13 Update KiCAD files and README
    [RedPyKeeb.kicad_pcb, RedPyKeeb.sch, led_strings.sch]
2021-03-20 Update KiCAD files, hopefully a working board this time.
    [RedPyKeeb-B_CrtYd.gbr, RedPyKeeb-B_Cu.gbr, RedPyKeeb-B_Fab.gbr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]
2021-03-21 Update KiCAD files to fix minor issues. Add initial release of firmware, not currently functioning.
    [RedPyKeeb-B_CrtYd.gbr, RedPyKeeb-B_Cu.gbr, RedPyKeeb-B_Fab.gbr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]
2021-03-31 Update KiCAD files.
    [RedPyKeeb-B_CrtYd.gbr, RedPyKeeb-B_Cu.gbr, RedPyKeeb-B_Fab.gbr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]
2021-04-06 Update firmware and KiCAD files.
    [RedPyKeeb-B_CrtYd.gbr, RedPyKeeb-B_Cu.gbr, RedPyKeeb-B_Fab.gbr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]
2021-04-13 KiCAD and firmware updates, first working firmware and half way through a board rewire after the initial semi-working board. Firmware has no real LED control other than the power budget system and pi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
    [RedPyKeeb.kicad_pcb, RedPyKeeb.sch, led_strings.sch]
2021-04-14 Update KiCAD and firmware files. Firmware has had a little bit of work to make sending key data easier. PCB has been fully routed for the 4th time and should be good to test LEDs and a much more popu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
    [RedPyKeeb-B_CrtYd.gbr, RedPyKeeb-B_Cu.gbr, RedPyKeeb-B_Fab.gbr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]
2021-04-16 Update KiCAD files for new BoM, new keyboard PCB and gerbers. Update Firmware to better support the keymap and for adding meta keys that drive the internal menu system to change values on the fly.
    [RedPyKeeb-B_CrtYd.gbr, RedPyKeeb-B_Cu.gbr, RedPyKeeb-B_Fab.gbr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]
2021-04-17 Update Firmware to use more of the interrupt data to make finding which keys are pressed way faster. Add board preview file from KiCAD.
2021-04-17 Firmware update to add initial LED support for some form of animation.
2021-04-18 Fimware update, this is as fast as I can get the leds to animate and keys to not lag.
2021-04-30 Split the PCB into 2 PCBs to allow for replacement MCUs and MCU boards while being able to test on the same key matrix and LED PCB. Lots of changes for firmware, really this is just what I have made 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
    [RedPyKeeb-B_CrtYd.gbr, RedPyKeeb-B_Cu.gbr, RedPyKeeb-B_Fab.gbr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]
2021-05-16 This is as-is before I test out a teensy MCU instead of the pico..
    [RedPyKeeb_MCU-B_CrtYd.gbr, RedPyKeeb_MCU-B_Cu.gbr, RedPyKeeb_MCU-B_Fab.gbr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]
2021-05-16 Timings on the teensy are amazing, so this will be the MCU of choice. A little annoying as I loved the pico for the Pyco name, so I'll just have to come up with something else.
    [RedPyKeeb_MCU-B_CrtYd.gbr, RedPyKeeb_MCU-B_Cu.gbr, RedPyKeeb_MCU-B_Fab.gbr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]
2021-06-16 Firmware is as-is for now, I've been testing PCB revisions and seeing what kind of latency I can poll the entire key matrix at KiCAD designs are looking really good now and I shoulld have parts in th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
    [RedPyKeeb_MCU-B_CrtYd.gbr, RedPyKeeb_MCU-B_Cu.gbr, RedPyKeeb_MCU-B_Fab.gbr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]
2021-07-27 Latest KiCAD files and what ever I had for testing the old boards.
    [RedPyKeeb_MCU-B_CrtYd.gbr, RedPyKeeb_MCU-B_Cu.gbr, RedPyKeeb_MCU-B_Fab.gbr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]
2021-09-01 NKRO is now supported and I've got what I believe to be working PCBs now
    [RedPyKeeb_MCU-B_CrtYd.gbr, RedPyKeeb_MCU-B_Cu.gbr, RedPyKeeb_MCU-B_Fab.gbr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]
2021-09-25 Minimum viable product! I still need to work out a few things on the PCBs but its finally real!
    [RedPyKeeb_MCU-B_CrtYd.gbr, RedPyKeeb_MCU-B_Cu.gbr, RedPyKeeb_MCU-B_Fab.gbr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]
2021-09-26 Add dip switch to allow for plug-in/boot time option selects. Add status light LEDs to be handled and actually reflect capslock and numlock status. Add tiny debounce which is enough on my prototype b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
    [RedPyKeeb_MCU-B_CrtYd.gbr, RedPyKeeb_MCU-B_Cu.gbr, RedPyKeeb_MCU-B_Fab.gbr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]
2021-10-16 Fix issues found with MCU and mainboard PCBs. Adding whatever fiddling I had with firmware.
    [RedPyKeeb_MCU-B.Cu.gbr, RedPyKeeb_MCU-B.Mask.gbr, RedPyKeeb_MCU-B.Paste.gbr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]
2021-10-17 Make more fixes and revisions to both PCBs, add in a pico for lighting and display functions and hook up an SPI bus with key event data.
    [RedPyKeeb_MCU-B.Cu.gbr, RedPyKeeb_MCU-B.Mask.gbr, RedPyKeeb_MCU-B.Paste.gbr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]
2022-02-02 Allow for dual MCU for lighting/display and key management
    [RedPyKeeb_MCU-B.Cu.gbr, RedPyKeeb_MCU-B.Mask.gbr, RedPyKeeb_MCU-B.Paste.gbr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]
